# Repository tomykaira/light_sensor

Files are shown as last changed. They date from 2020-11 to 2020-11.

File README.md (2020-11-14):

# Setup

This repository assumes STM32F103C8T6 board called Bluepill and ST-LINK V2 writer.
I use macOS.

Install required programs [for flash](https://alexbirkett.github.io/microcontroller/2019/03/30/flash_bluepill_using_ST_link.html) and [for build](https://github.com/stm32-rs/stm32f1xx-hal).

```
> st-info --probe
Found 1 stlink programmers
 serial:     402805012612344d314b4e00
 hla-serial: "\x40\x28\x05\x01\x26\x12\x34\x4d\x31\x4b\x4e\x00"
 flash:      0 (pagesize: 0)
 sram:       0
 chipid:     0x0004
```

`flash: 0` looks confusing, but no problem.

```
openocd -V -f interface/stlink-v2.cfg -f target/stm32f1x.cfg
```

At first, `Error: jtag status contains invalid mode value - communication failure` error may be printed.
In that case, press reset button on bluepill keeping openocd in the error status.
OpenOCD polls for connection, and next trial will succeed if reset button is pressed at that time.

```
cargo run --release
```

will start GDB session and stop before the start of program.

If it still does not work, run this magic code. I do not know why, but it is likely to start working.

```
st-flash read d 0x8000130 0xf88
```

These commands may also help.

```
(ocd) flash probe 0
(ocd) stm32f1x unlock 0
```

# Hardware

Current setup:

- Bluepill
- SG90 servo motor
- PSUP7C-02-NCL-16-1 infra-red motion sensor
- AAAA rechargeable battery (1.2V DC out) x 4
- 0.1uF decoupling capacitor around servo

Servo's PWM line is connected to PA0 (A0 on silk).
Infra-red sensor line is connected to PA7 (A7 on silk).
Infra-red sensor is sensitive to unstable power supply, so connected to regulated 3.3V of bluepill.

# LICENSE

You can use this product under MIT license.

Copyright 2020 tomykaira.

Permission is hereby granted, free of charge, to any person obtaining a copy of this software and associated documentation files (the "Software"), to deal in the Software without restriction, including without limitation the rights to use, copy, modify, merge, publish, distribute, sublicense, and/or sell copies of the Software, and to permit persons to whom the Software is furnished to do so, subject to the following conditions:

The above copyright notice and this permission notice shall be included in all copies or substantial portions of the Software.

THE SOFTWARE IS PROVIDED "AS IS", WITHOUT WARRANTY OF ANY KIND, EXPRESS OR IMPLIED, INCLUDING BUT NOT LIMITED TO THE WARRANTIES OF MERCHANTABILITY, FITNESS FOR A PARTICULAR PURPOSE AND NONINFRINGEMENT. IN NO EVENT SHALL THE AUTHORS OR COPYRIGHT HOLDERS BE LIABLE FOR ANY CLAIM, DAMAGES OR OTHER LIABILITY, WHETHER IN AN ACTION OF CONTRACT, TORT OR OTHERWISE, ARISING FROM, OUT OF OR IN CONNECTION WITH THE SOFTWARE OR THE USE OR OTHER DEALINGS IN THE SOFTWARE.

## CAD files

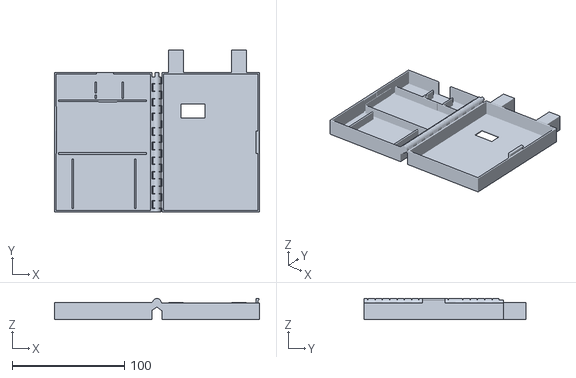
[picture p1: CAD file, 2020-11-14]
case/Hinged_Box.stl
182.3 x 143.8 x 18.9

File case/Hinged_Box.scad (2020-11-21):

$fn = 100;
wallThickness = 1.4;
inner_wall_thickness = 1.4;
inner_wall_offset = 3;
inner_wall_height = 8;
hingeOuter = 7;
hingeInner = 4;
hingeInnerSlop = .4;
hingeFingerSlop = .4;
fingerLength = hingeOuter/1.65;
fingerSize = 6.5;
latchWidth = 20;
z = 0;

bat_w = 54;
bat_d = 50;
bat_h = 12.5;

margin = 2;
d_margin = 0.3;

bread_d = 45 + margin;
bread_w = 83.6 + margin;
bread_h = 22.2;
sensor_sensor_d = 11.9 + margin;
sensor_sensor_w = 21 + margin;
sensor_body_w = 27.8 + margin;
sensor_body_d = 13.9 + margin;
sensor_offset_w = wallThickness + 20; // 20 is arbitrary
sensor_offset_d = wallThickness + 20; // 20 is arbitrary
sensor_h = 5.9;

prop_dia = 7;
prop_offset = 5;

outer_wall = 2;
wall_to_servo_lower = 10;
sw_panel_h_max = 8.6;
sw_panel_h_min = 5.6;

wiring_space = 5;

width = bread_w + wallThickness * 2;
depth = 22.7 + bread_d + bat_d + inner_wall_thickness * 2 + wallThickness * 2 ;
inner_height = bread_h + sensor_h;
height = (inner_height + wallThickness * 2) / 2;


topFingerSize = fingerSize;
pos = -depth/2;
mount_d = 20;

bottom();
top();

module bottom() {
	union() {
		// main box and cutout
		difference() {
			translate([-width - fingerLength, -depth/2, 0]) {
				bottom_content();
			}

			// latch cutout
			translate([-width - fingerLength + (wallThickness/2), (-latchWidth/2) - (hingeFingerSlop/2), wallThickness]) {
				cube([wallThickness/2 + .1, latchWidth + hingeFingerSlop, height]);
			}


		}

		//latch cylinder
		difference() {
			translate([-width - fingerLength + (wallThickness/2), -latchWidth/2, height - 1]) {
				rotate([-90,0,0]) {
					cylinder(r = 1, h = latchWidth);
				}
			}
			// front wall wipe
			translate([-width - fingerLength - 5, -depth/2,0]) {
				cube([5,depth,height]);
			}
		}

		difference() {
			hull() {
				translate([0,-depth/2,height]) {
					rotate([-90,0,0]) {
						cylinder(r = hingeOuter/2, h = depth);
					}
				}
				translate([-fingerLength - .1, -depth/2,height - hingeOuter]){
					cube([.1,depth,hingeOuter]);
				}
				translate([-fingerLength, -depth/2,height-.1]){
					cube([fingerLength,depth,.1]);
				}
				translate([0, -depth/2,height]){
					rotate([0,45,0]) {
						cube([hingeOuter/2,depth,.01]);
					}
				}
			}
			// finger cutouts

			for  (i = [-depth/2 + fingerSize:fingerSize*2:depth/2]) {
				translate([-fingerLength,i - (fingerSize/2) - (hingeFingerSlop/2),0]) {
					cube([fingerLength*2,fingerSize + hingeFingerSlop,height*2]);
				}
			}
		}

		// center rod
		translate([0, -depth/2, height]) {
			rotate([-90,0,0]) {
				cylinder(r = hingeInner /2, h = depth);
			}
		}
	}
}

module top() {
	union() {
		top_content();

		//latch
		translate([width + fingerLength - wallThickness - 1.5, (-latchWidth/2), 0]) {
			cube([1.5, latchWidth, height - .5 + 4]);
		}
		translate([width + fingerLength - wallThickness, -latchWidth/2, height - .5 + 3]) {
			rotate([-90,0,0]) {
				cylinder(r = 1, h = latchWidth);
			}
		}

		difference() {
			hull() {
				translate([0,-depth/2,height]) {
					rotate([-90,0,0]) {
						cylinder(r = hingeOuter/2, h = depth);
					}
				}
				translate([fingerLength, -depth/2,height - hingeOuter - .5]){
					cube([.1,depth,hingeOuter - .5]);
				}
				translate([-fingerLength/2, -depth/2,height-.1]){
					cube([fingerLength,depth,.1]);
				}
				translate([0, -depth/2,height]){
					rotate([0,45,0]) {
						cube([hingeOuter/2,depth,.01]);
					}
				}
			}
			// finger cutouts
			for  (i = [-depth/2:fingerSize*2:depth/2 + fingerSize]) {
				translate([-fingerLength,i - (fingerSize/2) - (hingeFingerSlop/2),0]) {
					cube([fingerLength*2,fingerSize + hingeFingerSlop,height*2]);
				}
				if (depth/2 - i < (fingerSize * 1.5)) {
					translate([-fingerLength,i - (fingerSize/2) - (hingeFingerSlop/2),0]) {
						cube([fingerLength*2,depth,height*2]);
					}
				}
			}

			// center cutout
			translate([0, -depth/2, height]) {
				rotate([-90,0,0]) {
					cylinder(r = hingeInner /2 + hingeInnerSlop, h = depth);
				}
			}
		}
	}
}

// dimensions:
// http://www.arduinoos.com/2016/02/sg90-servo-part-1/
module servo() {
	union() {
		cube([22.5, 22.7, 11.8]);
		translate([-4.7, 15.9, 0]) {
			cube([4.7, 2.5, 11.8]);
		}
		translate([22.5, 15.9, 0]) {
			cube([4.7, 2.5, 11.8]);
		}
		translate([0, 22.7, 0]) {
			cube([5.9 + 8.8, 4.0, 11.8]);
		}
		translate([5.9 - 4.6/2, 22.7+4.0, 11.8/2 - 4.6/2]) {
			cube([4.6, 3.2, 4.6]);
		}
		// cable
		translate([- 10, 4.5 - 1.2 * 0.5 / 2, 0]) {
			// w=10 can be any value, * 1.5 is for space
			cube([10, 1.2 * 1.5, 11.8]);
		}
	}
}

servo_w_offset = width / 2 - 5.9;
servo_h_offset = depth - 22.7 - wallThickness;
module bottom_content() {
	difference() {
		union() {
			cube([width, wallThickness, height]);
			translate([0, depth - wallThickness, 0])
				cube([width, wallThickness, height]);

			cube([wallThickness, depth, height]);
			translate([width - wallThickness, 0, 0])
				cube([wallThickness, depth, height]);

			difference () {
				cube([width, depth, wallThickness]);
				translate([0, -depth/1.41, 0])
					mesh([0 : width / mesh_pitch * 3], [0 : depth / mesh_pitch * 3]);
			}

			// content area
			translate([wallThickness, wallThickness, wallThickness]) {
				union() {
					// separators
					translate([(width - bat_w) / 2 + inner_wall_thickness / 2, inner_wall_thickness, 0]) {
						separator(bat_w, bat_d);
					}
					translate([(width - bread_w) / 2 + inner_wall_thickness / 2, inner_wall_thickness * 2 + bat_d, 0]) {
						separator(bread_w, bread_d);
					}
					translate([servo_w_offset, servo_h_offset - margin / 2, 0]) {
						separator(22.5, 22.7);
					}
				}
			}

			// TOOD verify X position
			translate([(11.55), depth, 0]) {
				cube([13.25, mount_d ,height]);
			}
			translate([((11.55 + 13.25 + 43)), depth, 0]) {
				cube([13.25, mount_d ,height]);
			}
		}
		// servo window
		translate([servo_w_offset, servo_h_offset, wallThickness]) {
			union() {
				servo();
				translate([0, 22.7, 0]) {
					cube([5.9 + 8.8, 4.0, 30]); // extend height
				}

			}
		}
	}
}


module separator(w, d) {
	translate([-inner_wall_offset, -inner_wall_offset, 0]) {
		union() {
			translate([0, inner_wall_offset, 0]) {
				cube([inner_wall_thickness, d - inner_wall_offset * 2, inner_wall_height]);
			}
			translate([w + inner_wall_thickness, inner_wall_offset, 0]) {
				cube([inner_wall_thickness, d - inner_wall_offset * 2, inner_wall_height]);
			}
			translate([inner_wall_offset, 0, 0]) {
				cube([w - inner_wall_offset * 2, inner_wall_thickness,, inner_wall_height]);
			}
			translate([inner_wall_offset, d + inner_wall_thickness, 0]) {
				cube([w - inner_wall_offset * 2, inner_wall_thickness, inner_wall_height]);
			}
		}
	}
}

mesh_pitch = 5;
mesh_hole_size = 3;
module mesh(x_range, y_range) {
	for ( i = y_range )
	{
		for (j = x_range ) {
			rotate(45, [0, 0, 1])
				translate([j * mesh_pitch, i * mesh_pitch, 0])
				cube(mesh_hole_size, mesh_hole_size, wallThickness);
		}
	}
}

module top_content() {
	union() {
		difference() {

			translate([fingerLength, -depth/2, 0]) {
				cube([width,depth,height - .5]);
			}

			translate([fingerLength + wallThickness, -depth/2 + wallThickness, wallThickness]) {
				cube([width - (wallThickness * 2), depth - (wallThickness * 2), height]);
			}
			translate([sensor_offset_w, sensor_offset_d, 0]) {
				cube([sensor_sensor_w, sensor_sensor_d, wallThickness]);
			}
		}
	}
}

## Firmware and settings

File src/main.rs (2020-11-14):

#![no_std]
#![no_main]

use embedded_hal::digital::v2::{InputPin, OutputPin};
// you can put a breakpoint on `rust_begin_unwind` to catch panics
use cortex_m::peripheral::DWT;
use rtic::app;
use rtic::cyccnt::U32Ext as _;
use stm32f1xx_hal::gpio::gpioa::PA7;
use stm32f1xx_hal::gpio::{Edge, Floating, Input};
use stm32f1xx_hal::pwm::{PwmChannel, C1};
use stm32f1xx_hal::timer::{Tim2NoRemap, Timer};
use stm32f1xx_hal::{
    gpio::{gpioc::PC13, ExtiPin, Output, PushPull},
    pac::TIM2,
    prelude::*,
};

use panic_halt as _;

// use panic_semihosting as _;
// use cortex_m_semihosting::hprintln;

// Standard clock of bluepill is 8MHz.
// Because the servo is 50 Hz, we set 40 ms (2 PWM signals).
const SERVO_OFF_PERIOD: u32 = 320_000; // = 8000 x 40
                                       // Bluepill clock speed is 8MHz.
const CLOCK_SPEED: u32 = 8_000_000; // 8 MHz
                                    // We wait at least this seconds to turn light off.
const LIGHT_OFF_SEC: u16 = 60;

const ON_ANGLE: u16 = 6;
const OFF_ANGLE: u16 = 3;

#[app(device = stm32f1xx_hal::pac, peripherals = true, monotonic = rtic::cyccnt::CYCCNT)]
const APP: () = {
    struct Resources<P> {
        led: PC13<Output<PushPull>>,
        int_pin: PA7<Input<Floating>>,
        servo: PwmChannel<TIM2, C1>,
        #[init(0)]
        seconds_to_off: u16,
    }

    #[init(schedule = [tick_second])]
    fn init(mut cx: init::Context) -> init::LateResources {
        cx.core.DCB.enable_trace();
        DWT::unlock();
        cx.core.DWT.enable_cycle_counter();
        // Take ownership over the raw flash and rcc devices and convert them into the corresponding
        // HAL structs
        let mut flash = cx.device.FLASH.constrain();
        let mut rcc = cx.device.RCC.constrain();

        let clocks = rcc.cfgr.freeze(&mut flash.acr);

        let mut afio = cx.device.AFIO.constrain(&mut rcc.apb2);

        // Acquire the GPIOx peripheral
        let mut gpioa = cx.device.GPIOA.split(&mut rcc.apb2);
        let mut gpioc = cx.device.GPIOC.split(&mut rcc.apb2);

        let c1 = gpioa.pa0.into_alternate_push_pull(&mut gpioa.crl);
        let pins = c1;
        let pwm = Timer::tim2(cx.device.TIM2, &clocks, &mut rcc.apb1).pwm::<Tim2NoRemap, _, _, _>(
            pins,
            &mut afio.mapr,
            50.hz(),
        );
        let servo = pwm.split();

        // Configure gpio C pin 13 as a push-pull output. The `crh` register is passed to the
        // function in order to configure the port. For pins 0-7, crl should be passed instead
        let mut led = gpioc.pc13.into_push_pull_output(&mut gpioc.crh);
        // Init to OFF.
        led.set_high().unwrap();

        let mut int_pin = gpioa.pa7.into_floating_input(&mut gpioa.crl);

        int_pin.make_interrupt_source(&mut afio);
        int_pin.trigger_on_edge(&cx.device.EXTI, Edge::RISING_FALLING);
        int_pin.enable_interrupt(&cx.device.EXTI);

        // Init the static resources to use them later through RTFM
        init::LateResources {
            led,
            int_pin,
            servo,
        }
    }

    // Optional.
    //
    // https://rtfm.rs/0.5/book/en/by-example/app.html#idle
    // > When no idle function is declared, the runtime sets the SLEEPONEXIT bit and then
    // > sends the microcontroller to sleep after running init.
    #[idle(spawn=[tick_second, turn_light_off])]
    fn idle(cx: idle::Context) -> ! {
        cx.spawn.tick_second().unwrap();
        cx.spawn.turn_light_off().unwrap();
        loop {
            cortex_m::asm::wfi();
        }
    }

    #[task(binds = EXTI9_5, priority = 1, resources = [led, int_pin, servo, seconds_to_off], schedule = [turn_servo_off, tick_second])]
    #[allow(unused_must_use)] // <= We must not call unwrap() on them. They become Err().
    fn change(cx: change::Context) {
        // if we don't clear this bit, the ISR would trigger indefinitely
        cx.resources.int_pin.clear_interrupt_pending_bit();

        // Active low
        if cx.resources.int_pin.is_low().unwrap() {
            if *cx.resources.seconds_to_off == 0 {
                cx.resources.led.set_low().unwrap();
                cx.resources.servo.enable();
                let max = cx.resources.servo.get_max_duty();
                cx.resources.servo.set_duty((max / 100) * ON_ANGLE);
                cx.schedule
                    .turn_servo_off(cx.start + SERVO_OFF_PERIOD.cycles());

                cx.schedule
                    .tick_second(cx.start + CLOCK_SPEED.cycles())
                    .unwrap();
            }

            *cx.resources.seconds_to_off = LIGHT_OFF_SEC;
        }
    }

    #[task(resources = [seconds_to_off], schedule = [tick_second], spawn=[turn_light_off])]
    fn tick_second(cx: tick_second::Context) {
        if *cx.resources.seconds_to_off == 0 {
            cx.spawn.turn_light_off().unwrap();
        } else {
            *cx.resources.seconds_to_off -= 1;
            cx.schedule
                .tick_second(cx.scheduled + CLOCK_SPEED.cycles())
                .unwrap();
        }
    }

    #[task(resources=[servo, led, seconds_to_off], schedule = [turn_servo_off, turn_light_off])]
    #[allow(unused_must_use)] // <= We must not call unwrap() on them. They become Err().
    fn turn_light_off(cx: turn_light_off::Context) {
        cx.resources.led.set_low().unwrap();
        cx.resources.servo.enable();
        let max = cx.resources.servo.get_max_duty();
        cx.resources.servo.set_duty((max / 100) * OFF_ANGLE);
        cx.schedule
            .turn_servo_off(cx.scheduled + SERVO_OFF_PERIOD.cycles());
        *cx.resources.seconds_to_off = 0;
    }

    #[task(resources=[servo, led])]
    fn turn_servo_off(cx: turn_servo_off::Context) {
        cx.resources.led.set_high().unwrap();
        cx.resources.servo.disable();
    }

    // RTIC requires that unused interrupts are declared in an extern block when
    // using software tasks; these free interrupts will be used to dispatch the
    // software tasks.
    extern "C" {
        fn TIM2();
    }
};

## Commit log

2020-09-20 IR human sensor with LED
    Use WFI and EXTI for low battery consumption.
2020-09-24 Install servo
2020-10-03 Servo and sensor with RTIC
2020-11-14 Update to be reusable
    [Hinged_Box.scad, Hinged_Box.stl]
2020-11-21 Update case
    wip
    [Hinged_Box.scad]
